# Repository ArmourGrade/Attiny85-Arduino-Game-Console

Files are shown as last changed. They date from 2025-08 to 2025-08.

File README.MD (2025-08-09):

# DIY Attiny Arduino Keychain Game Console

This repo features the Schematic file, Gerber files and Bill Of material. Feel free to use the files and modify them as you wish.

### YOUTUBE VIDEO CLICK ON PICTURE
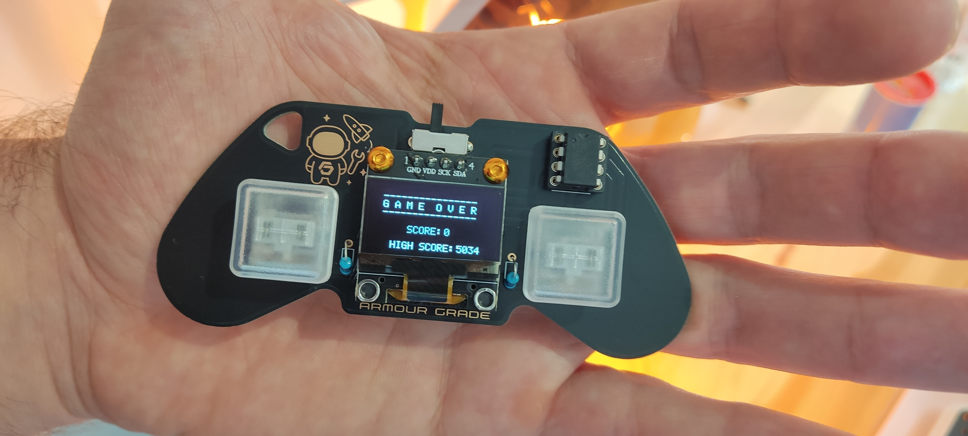
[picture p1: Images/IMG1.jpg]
Attiny_Arcade (https://www.youtube.com/watch?v=D4EZ1D5AoRs&t=7s)


Please note that if you plan on using these gerber (Version 1 of files) files you should flip the coin battery holder during assembly in comparisson to the outline drawn on the PCB for easier replacement of the battery due to close proximity with the switch pins. (Like in the picture bellow)
No additional changes need to be made for this, since the polarity is the same of both left and right pins. (This can be seen in the video)

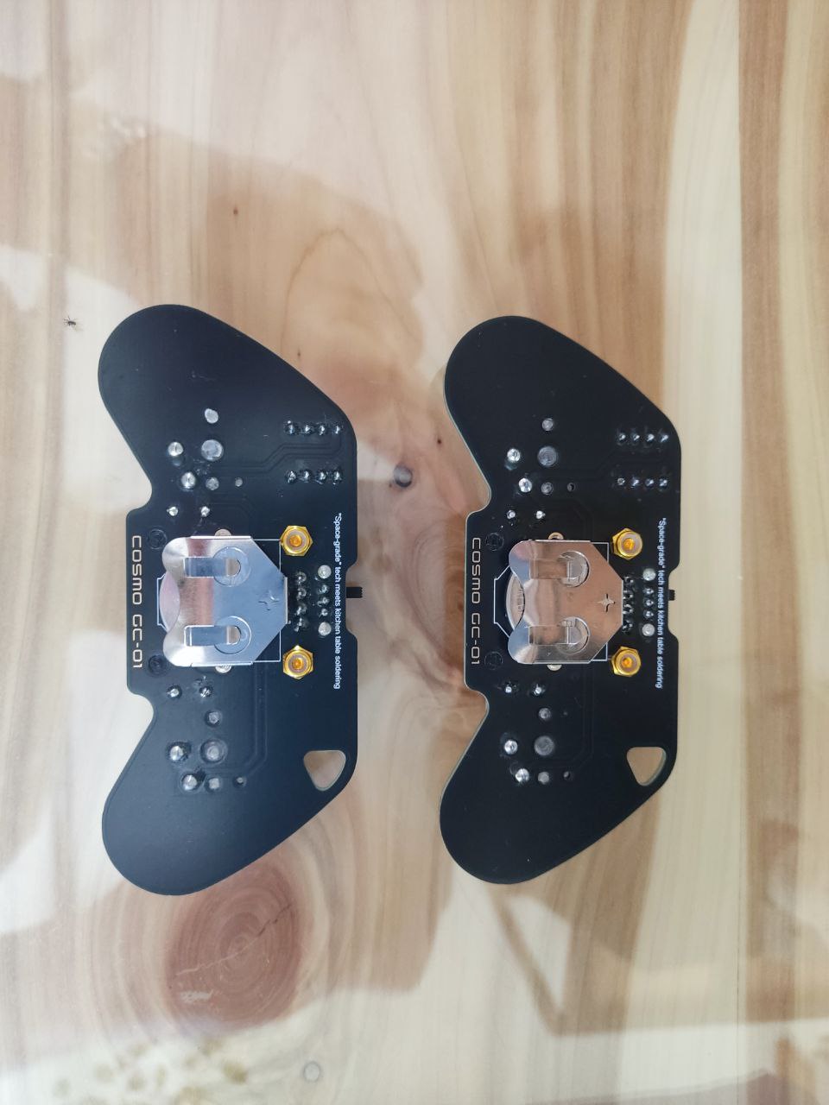
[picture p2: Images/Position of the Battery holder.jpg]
Attiny_Arcade_fix


### Version 1.1 of gerbers (Minor Updates)(Not tested but should work)
I have uploaded a new version of the Gerber files where the footprint is already flipped, This version also features some minor changes.

Through hole resistors changed for SMD.

Added decoupling capacitors to the Micro and Buzzer Driver IC.

PAD sizes increased.

Before soldering the Battery holder you should put a little solder on the PAD thats represents the other polarity of the Battery, as shown in the video. This is so that the battery will have better conntact with the Pad.

The firmware used in the project is from: https://github.com/andyhighnumber/Attiny-Arduino-Games

## Bill of Materials
1. SSD1306 OLED with I2C
2. Attiny85_20PU
3. DIP8P socket 
4. 2x Kailh choch v1 switches and keycaps
5. 2x 10k through-hole resistors (for version 1.1 I used 1206 SMD resistors also 10kOhm)
6. SN74LVC2G04DBVR
7. CPT-1203-78-SMT-TR (buzzer speaker)
8. EG1213 (switch)
9. Keystone Electronics 3003 (Battery Holder)
10. (Version 1.1) 2x 0805 100nF capacitors X7R

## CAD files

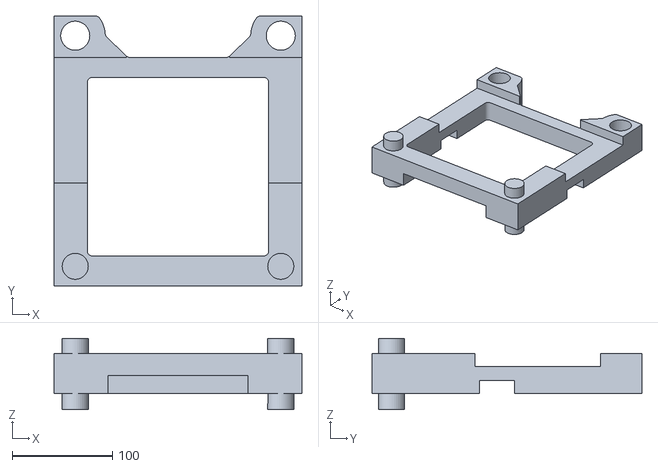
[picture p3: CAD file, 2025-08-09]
Spacer for OLED 3D Model/Display spacer for both Cosmo versions.stl
247.0 x 269.3 x 71.0

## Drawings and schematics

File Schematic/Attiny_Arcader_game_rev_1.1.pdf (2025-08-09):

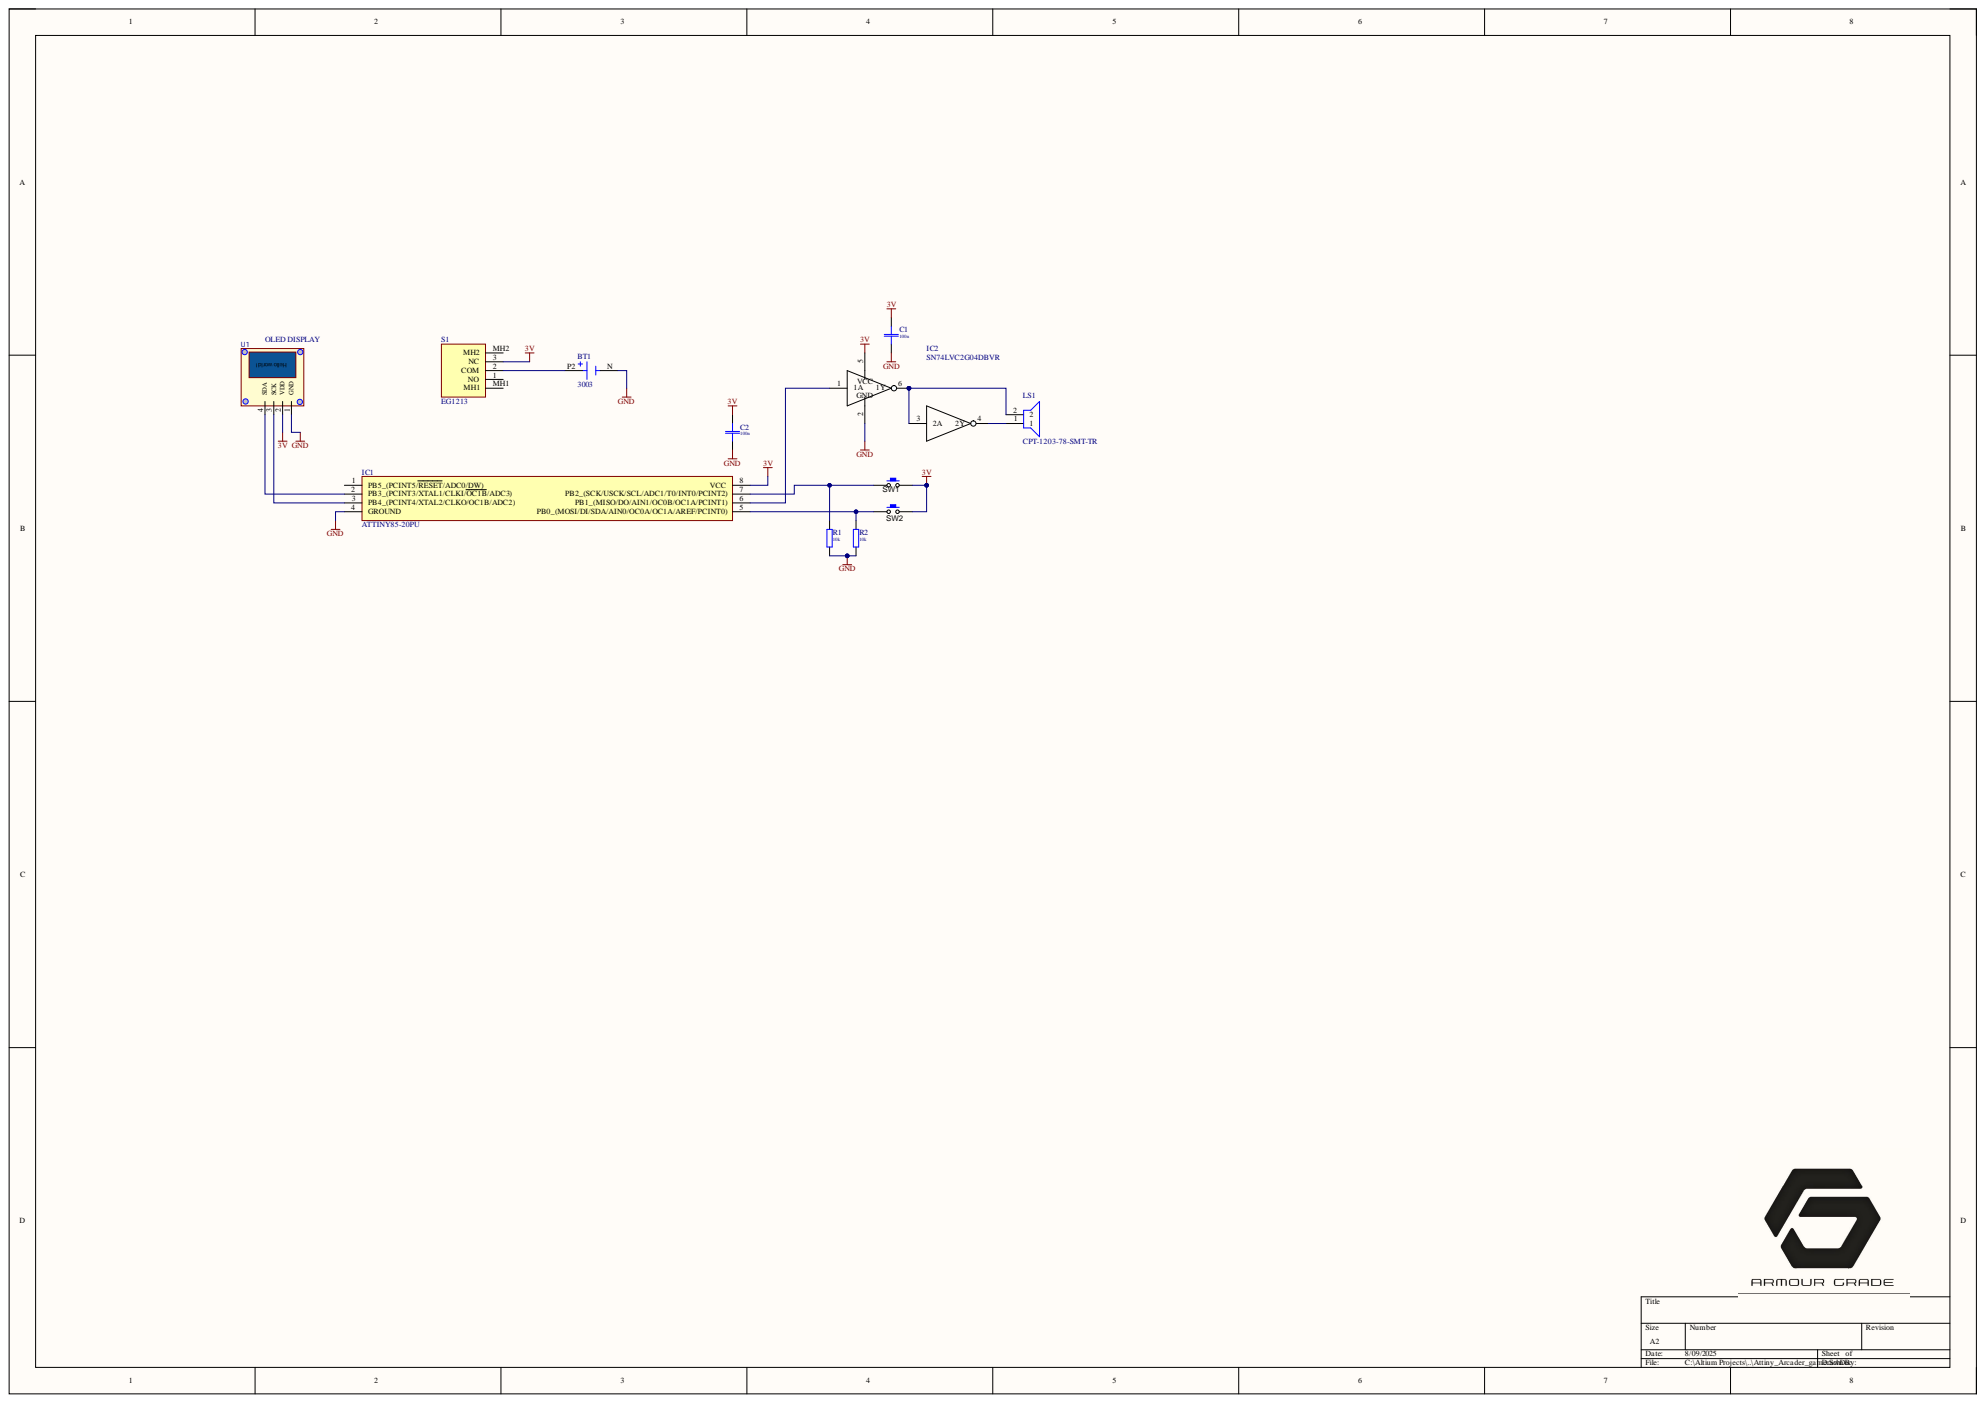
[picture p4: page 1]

Comment | Description | Designator | Footprint | LibRef | Quantity
3003 | Battery Holder: THM, 1 Coin Cell, 20mm, PhosBronze/Tin-Nickel | Keystone Electronics 3003 | BT1 | BAT_3003_REWORK | 3003 | 1
100n | SMD-0805 50V X7R 10% | C1, C2 | C0805(2013) | C-0805 50V X7R | 2
ATTINY85-20PU | Integrated Circuit | IC1 | DIP781W56P254L950 H533Q8N | ATTINY85-20PU | 1
SN74LVC2G04DBVR | Integrated Circuit | IC2 | SOT95P280X145-6N | SN74LVC2G04DBVR | 1
CPT-1203-78-SMT-TR | Loudspeaker or Buzzer | LS1 | CPT120378SMTTR | CPT-1203-78-SMT-TR | 1
10k | 0.125W 5% 200V | R1, R2 | R1206 | R-0.125W | 2
EG1213 | Switch | S1 | EG1213 | EG1213 | 1
SW_PB_SPST_HDR | | SW1, SW2 | Kailh Choc | SWPBT_SPST_HDR | 2
OLED DISPLAY | | U1 | oled Arduino - SMD | OLED DISPLAY | 1

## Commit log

2025-08-01 Uploaded Schematic PDF, gerbers and initial description
2025-08-02 Add files via upload
    This image is to show the orientation of the battery holder should be placed opposite of the outline that is on the PCB. The reason for this is because the proximity of the switch pins could make it a bit more difficult to to replace the battery. No other modification needed
2025-08-02 Update README.MD
    Added info on positioning of Battery holder
2025-08-09 New Schematic 1.1 has Decoupling Caps added,Gerbers 1.1 have flipped Battery holder
2025-08-09 Added 3D model of Display Spacer so you can print it out
    [Display spacer for both Cosmo versions.stl]
